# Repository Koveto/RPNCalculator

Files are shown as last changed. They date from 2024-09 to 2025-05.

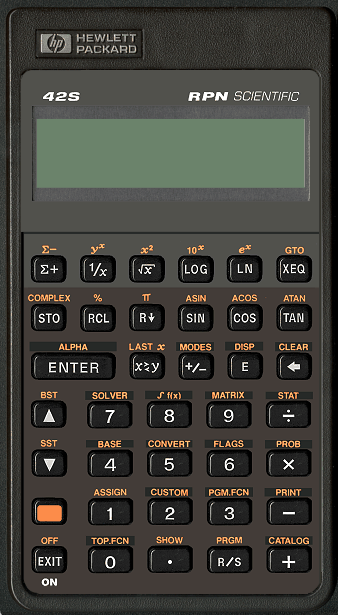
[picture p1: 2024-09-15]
background.png

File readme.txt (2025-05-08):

Reverse Polish Notation (RPN) Calculator

Contributors:
Kale Erickson
Kobe Goodwin
Gabe Wichmann

NDSU Senior Design project
ECE 403/405
Fall 2024 - Spring 2025
OneNote: https://ndusbpos-my.sharepoint.com/:o:/g/personal/kale_erickson_ndus_edu/EvFGwJnf-eBBiN7WtRWUvscBkYgOqBa3zW2gMm88qsdTBQ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

Project Description

HP-42S is a reverse polish notation (RPN) calculator championed by 
engineers around the world. RPN calculators sell for $400 and higher:
a forbidding price for college students. Our committee will design an
alternative HP-42S calculator that is affordable and reliable. Our 
RPN calculator solution will operate on mobile hardware powered by a
battery and disconnected from external devices. Our committee aims to
construct a RPN calculator engineering students could feasibly use on
exams. 

Instructions

1. Hold the button on the Raspberry Pi Pico
2. Plug the Pico into the computer
3. Drag "rp2-pico-micropython-doubleprecision-1-19.uf2" into the new directory
4. Unplug the Pico
5. Release the button
6. Plug the Pico into the computer
7. Use Thonny to save files in "program" to Pico

About the LCD

The program includes lcd.py and lcd_i2c.py.
lcd.py:
   communicates to the 20x4 LCD (using parallel interface)
lcd_i2c.py:
   NOT NECESSARY TO DOWNLOAD.
   used by an old PCB revision to communicate to its 16x2 LCD
   (using I2C protocol). 
To switch from one to the other,
   remove commented-out LCD_I2C import/initialization in main.py.
   comment out LCD import/initialization in main.py. 
Different LCD?
   the program only supports 20x4 parallel or 16x2 I2C.
   change ROWS and COLUMNS in lcd.py or lcd_i2c.py.
   revise lcd.write_to(...) commands in main.py and calculator.py.

Program your own game!

lcd.py is necessary.
Revise button_labels.py with your buttons and mapping.
Revise push_buttons.py if necessary.
Create your own main.py to read input and display output.

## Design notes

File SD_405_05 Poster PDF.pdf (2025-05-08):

# RPN Calculator

## Team Members: Kale Erickson, Kobe Goodwin, Gabe Wichmann

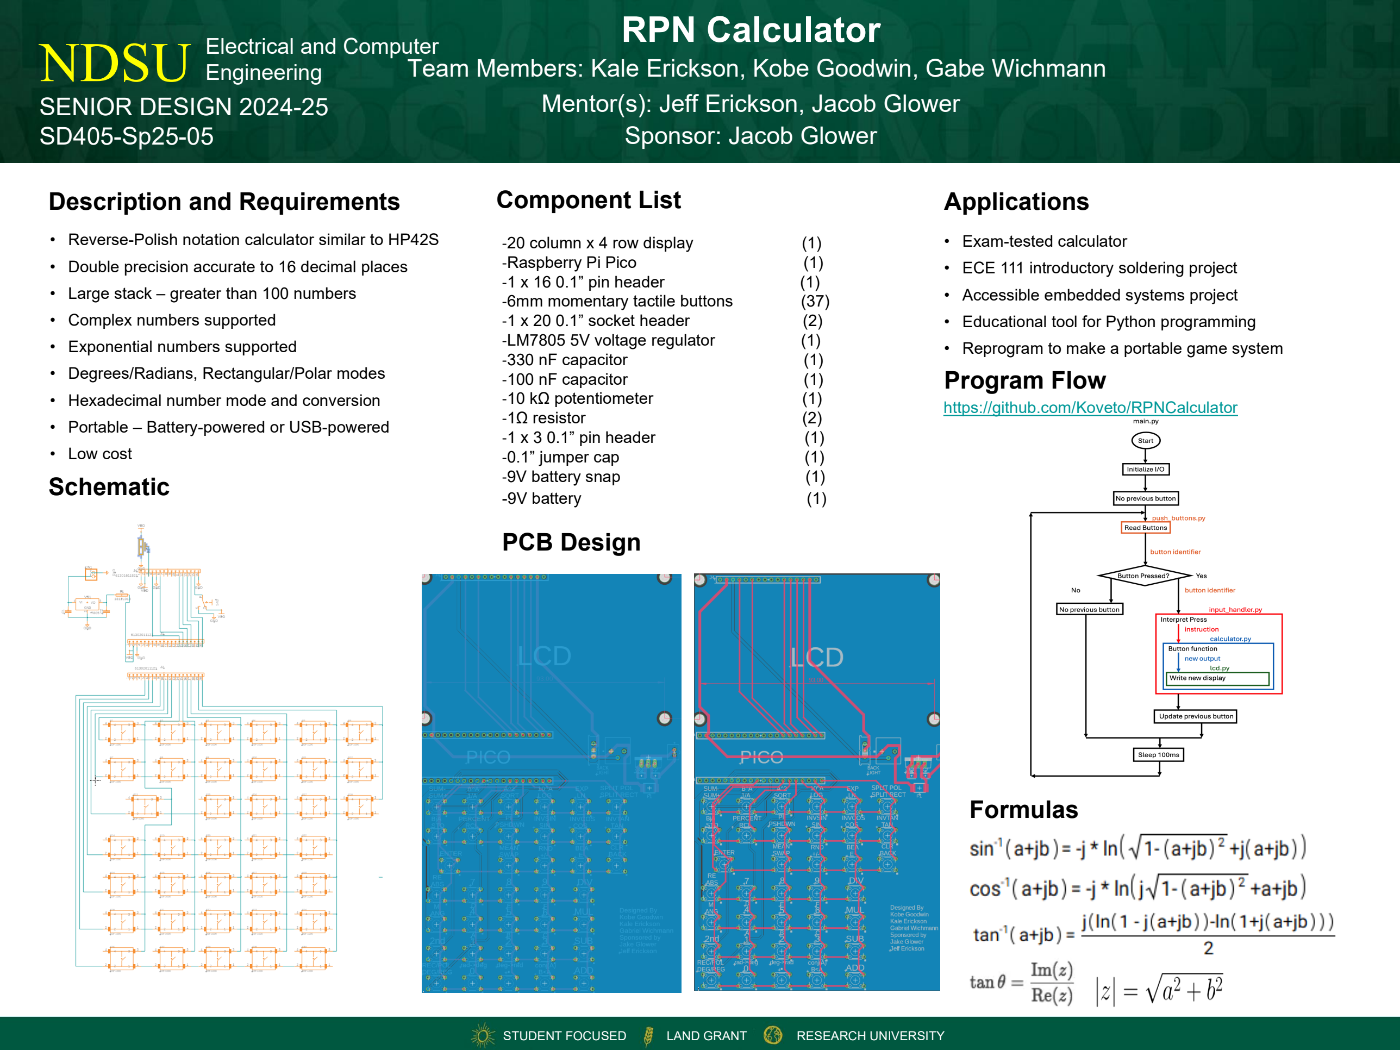
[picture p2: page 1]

STUDENT FOCUSED | LAND GRANT | RESEARCH UNIVERSITY

## Mentor(s): Jeff Erickson, Jacob Glower Sponsor: Jacob Glower

## SENIOR DESIGN 2024-25 SD405-Sp25-05

## Description and Requirements

- Reverse-Polish notation calculator similar to HP42S
- Double precision accurate to 16 decimal places
- Large stack – greater than 100 numbers
- Complex numbers supported
- Exponential numbers supported
- Degrees/Radians, Rectangular/Polar modes
- Hexadecimal number mode and conversion
- Portable – Battery-powered or USB-powered
- Low cost

## NDSU Electrical and Computer Engineering

Component List | Applications
| • Exam-tested calculator • ECE 111 introductory soldering project • Accessible embedded systems project • Educational tool for Python programming • Reprogram to make a portable game system
-20 column x 4 row display | (1)
-Raspberry Pi Pico | (1)
-1 x 16 0.1” pin header | (1)
-6mm momentary tactile buttons | (37)
-1 x 20 0.1” socket header | (2)
-LM7805 5V voltage regulator | (1)
-330 nF capacitor | (1)
-100 nF capacitor | (1)
-10 kΩ potentiometer | (1)
-1Ω resistor | (2)
-1 x 3 0.1” pin header | (1)
-0.1” jumper cap | (1)
-9V battery snap | (1)
-9V battery | (1)

## Program Flow

https://github.com/Koveto/RPNCalculator

## Schematic

## PCB Design

## Formulas

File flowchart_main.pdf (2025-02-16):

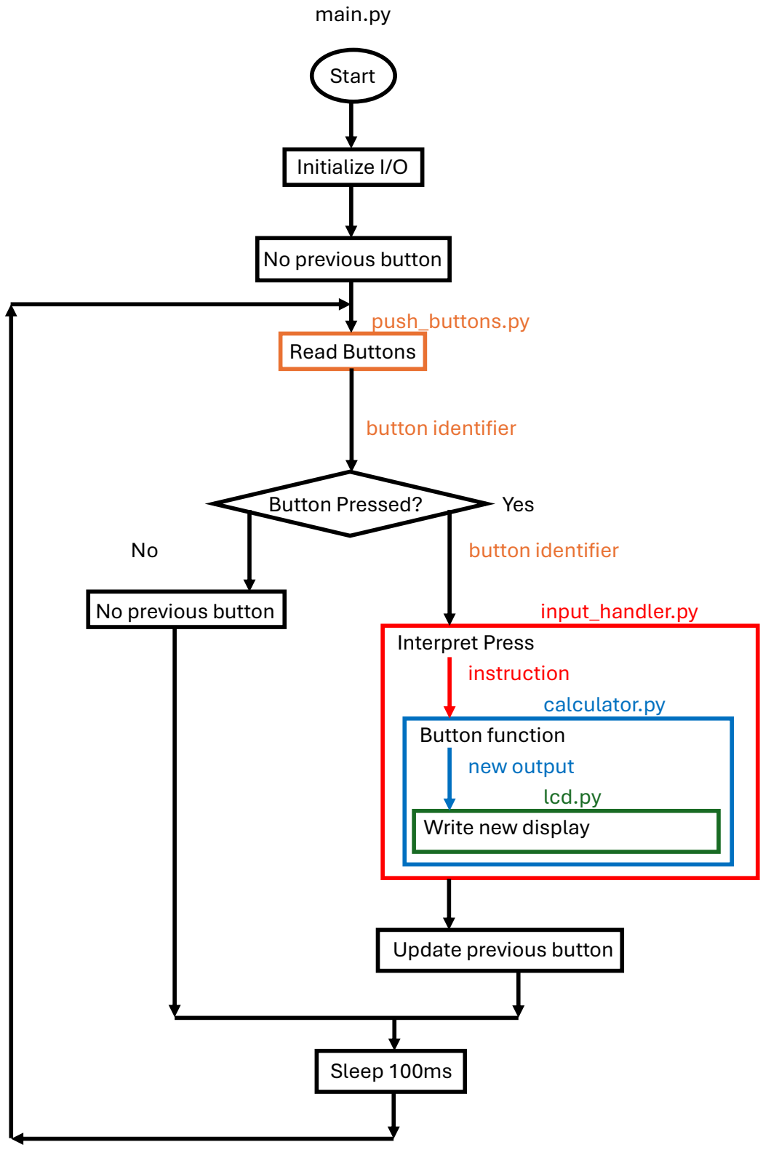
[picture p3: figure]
main.py; Start; Initialize I/O; No previous button; push_buttons.py Read Buttons; button identifier; Button Pressed?; Yes; input_handler.py; Interpret Press instruction calculator.py Button function new output lcd.py Write new display; Update previous button; Sleep 100ms

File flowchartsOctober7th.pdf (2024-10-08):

addition(Z)
Add top numbers from stack, subtract where Z = -1
Ex. | Z = 1 | (Addition) | Ex. | Z = -1 | (Subtraction)

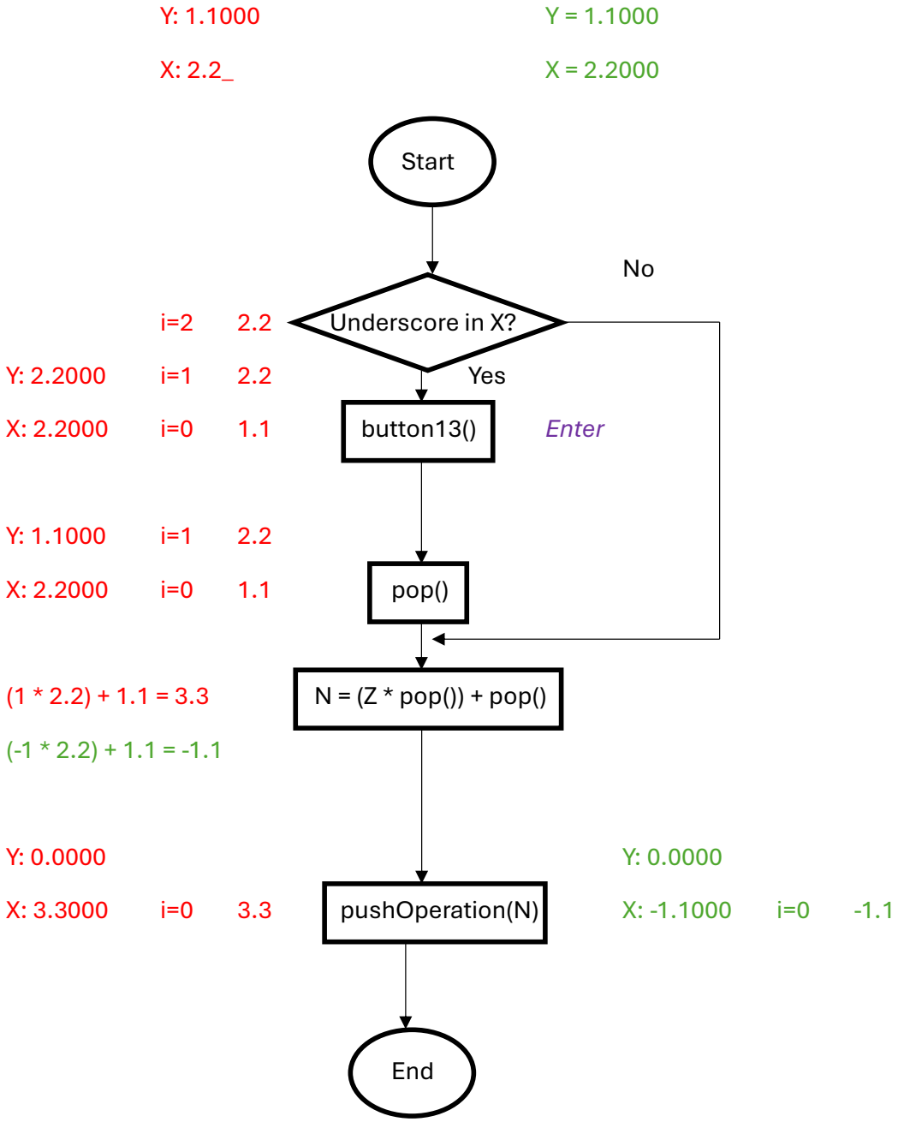
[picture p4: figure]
Start; Underscore in X?; Yes; button13(); Enter; pop(); pushOperation(N); End

(1 * 2.2) + 1.1 = 3.3 | N = (Z * pop()) + pop()

appendZeros(text)
Format text to add zeros
Ex. ”1” -> ”1.0000”
Ex. ”5.2” -> ”5.2000”
Ex. “3.14159” -> “3.14159”

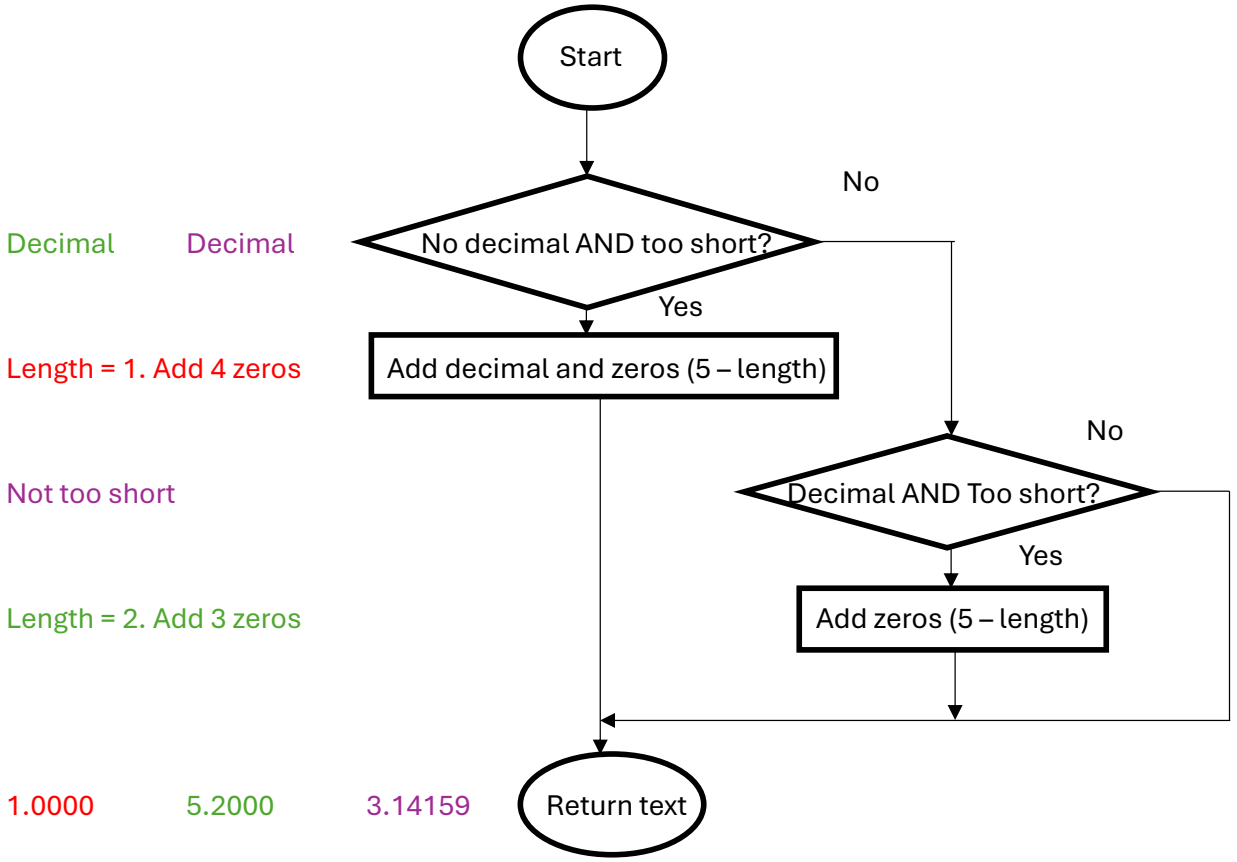
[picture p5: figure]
Start; Decimal; No decimal AND too short?; Yes; Not too short; Decimal AND Too short?; Return text

Length = 1. Add 4 zeros | Add decimal and zeros (5 – length)
Length = 2. Add 3 zeros | Add zeros (5 – length)

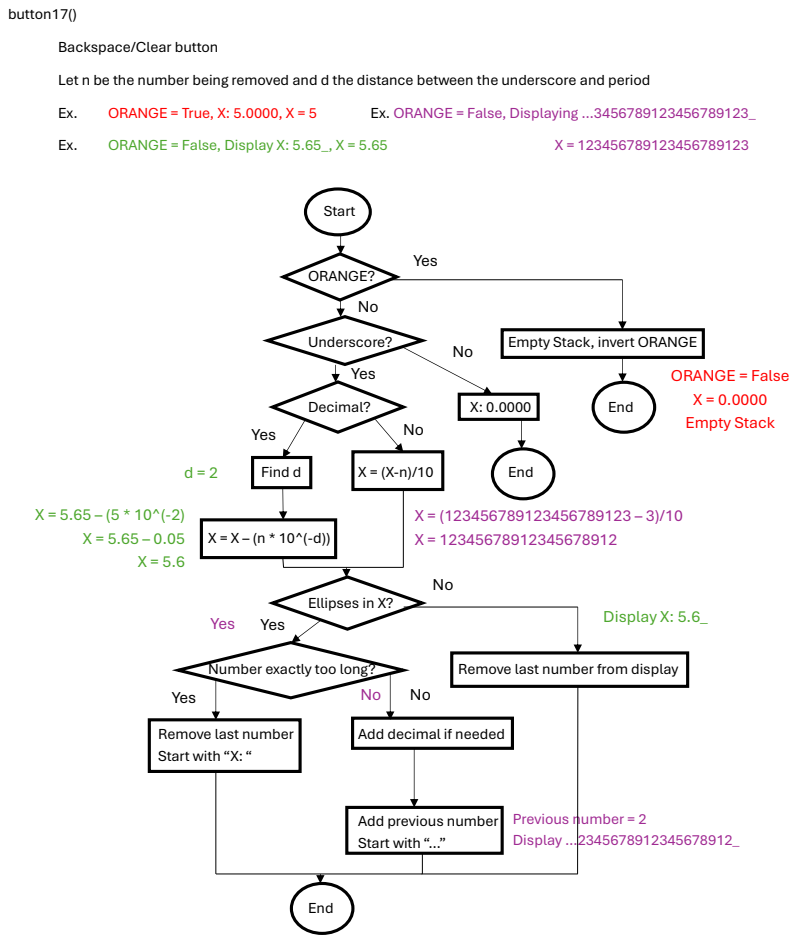
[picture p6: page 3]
Yes; ORANGE = False X = 0.0000 Empty Stack; Previous number = 2 Display …2345678912345678912_; ORANGE = True, X: 5.0000, X = 5; Ex. ORANGE = False, Displaying …3456789123456789123_; ORANGE = False, Display X: 5.65_, X = 5.65; Start; ORANGE?; Underscore?; Empty Stack, invert ORANGE; Decimal?; End; Find d; Ellipses in X?; Number exactly too long?; Remove last number from display; Remove last number; Add decimal if needed; Start with “X: “; Display X: 5.6_

button17()
Backspace/Clear button
Let n be the number being removed and d the distance between the underscore and period

Add previous number
Start with “…”

button22()
“Divide” button
Ex. | i=1 | 0 | Y: 2.0000 | Ex. | Y: 9.0000
i=0 | 2 | X: 0.0000 | i=0 | 9 | X: 3_
Outcome:
Divide By Zero | Y: 0.0000
X: 0.0000 | i=0 | 3 | X: 3.0000

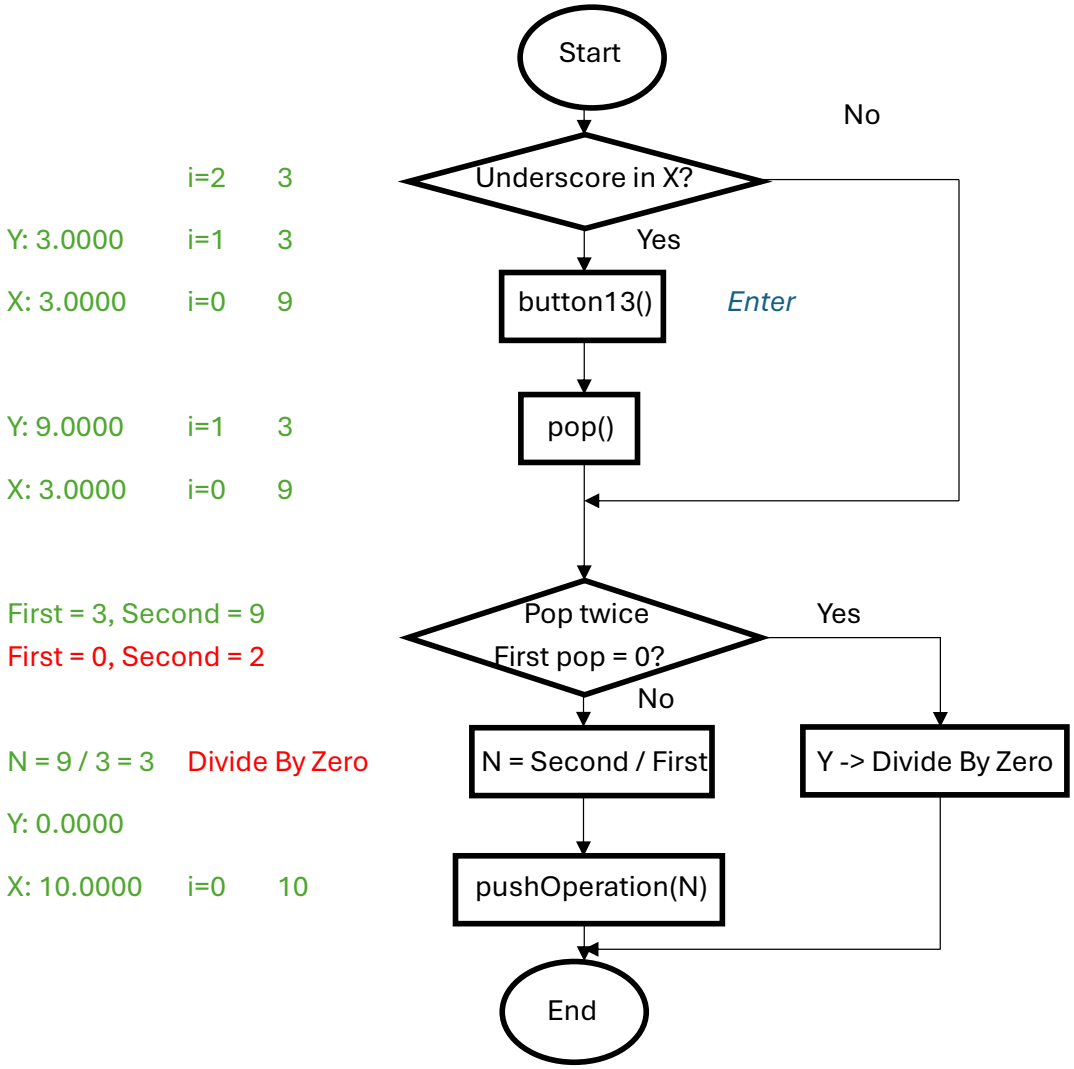
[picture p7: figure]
Start; Underscore in X?; Yes; button13(); Enter; pop(); First = 3, Second = 9; Pop twice; First = 0, Second = 2; First pop = 0?; pushOperation(N); End

N = 9 / 3 = 3 Divide By Zero | N = Second / First | Y -> Divide By Zero

button27()
"Multiply" button. Calls button13() and pop() to add the current number (if any) once to the stack. Pops twice from the stack and multiplies. Calls pushOperation(number) to update the stack and display.
Ex. | i=1 | 5 | Y: 2.0000 | Ex. | Y: 3.0000
i=0 | 2 | X: 5.0000 | i=0 | 3 | X: 4_
Outcome:
Y: 0.0000 | Y: 0.0000
i=0 | 10 | X: 10.0000 | i=0 | 12 | X: 12.0000

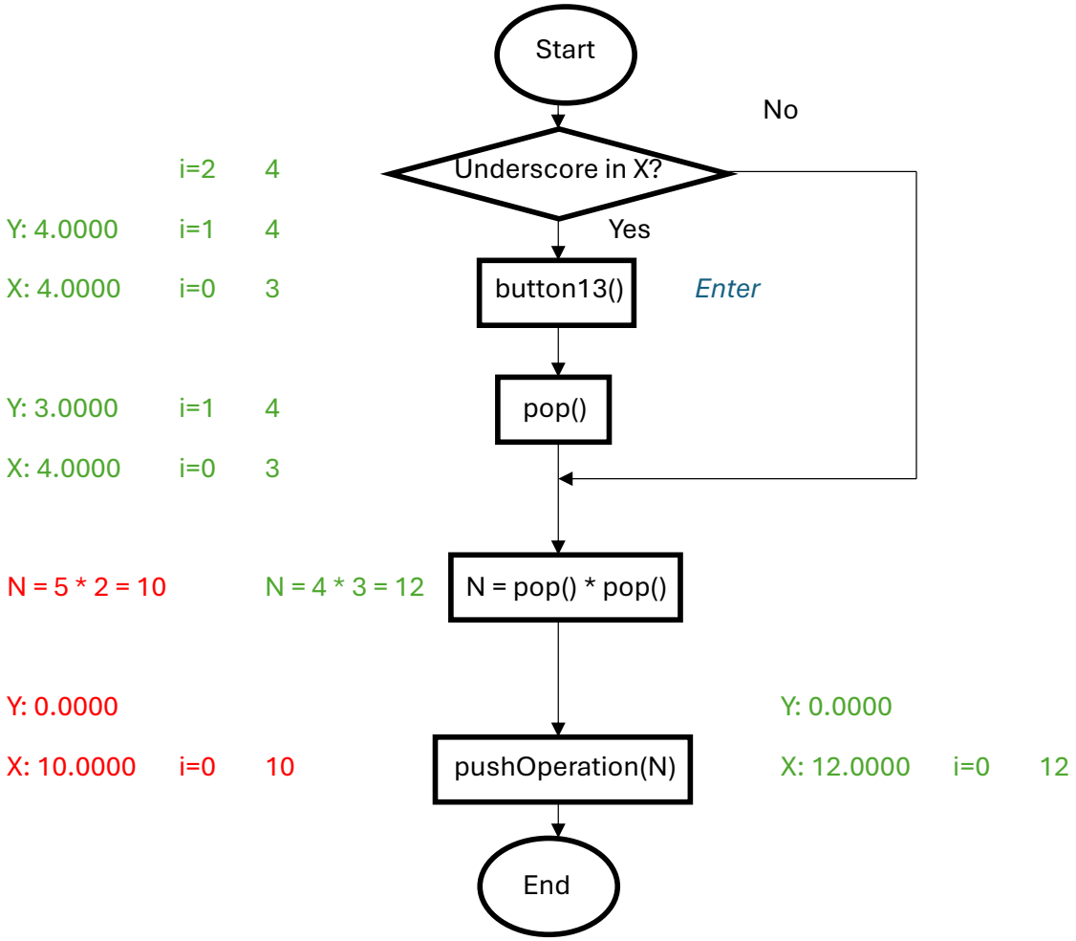
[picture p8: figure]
Start; Underscore in X?; Yes; button13(); Enter; pop(); pushOperation(N); End

N = 5 * 2 = 10 | N = 4 * 3 = 12 | N = pop() * pop()

button35()
Decimal button. Does nothing if a number is being input and already has a decimal place. Starts a new number at "0._" if no number is being input. Otherwise, adds "._" to the display and scrolls if necessary.
Ex. | X: 0.02_ | Ex. | X: 5.0000 | Ex. | …1234567891234567891_
numX = 0.02 | numX = 5 | numX = 1234567891234567891
Outcome:
| X: 0.02_ | | X: 0._ | | …234567891234567891._
numX = 0.02 | numX = 0 | numX = 1234567891234567891

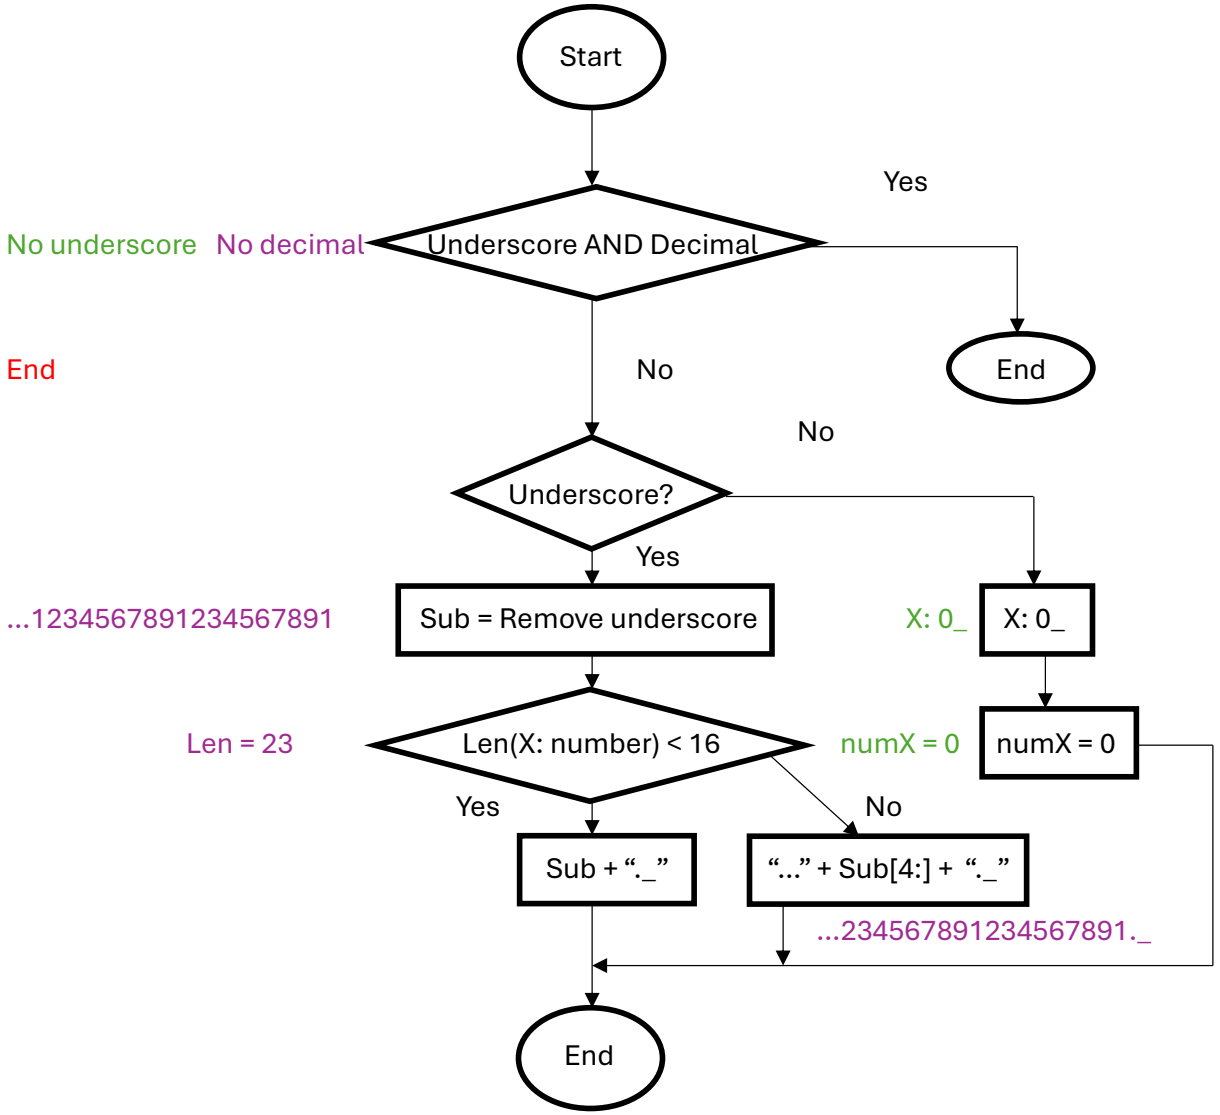
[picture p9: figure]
Start; Yes; No underscore No decimal; Underscore AND Decimal; End; Underscore?; Sub = Remove underscore; Len = 23; Len(X: number) < 16; numX = 0; Sub + “._”; “…” + Sub[4:] + “._”

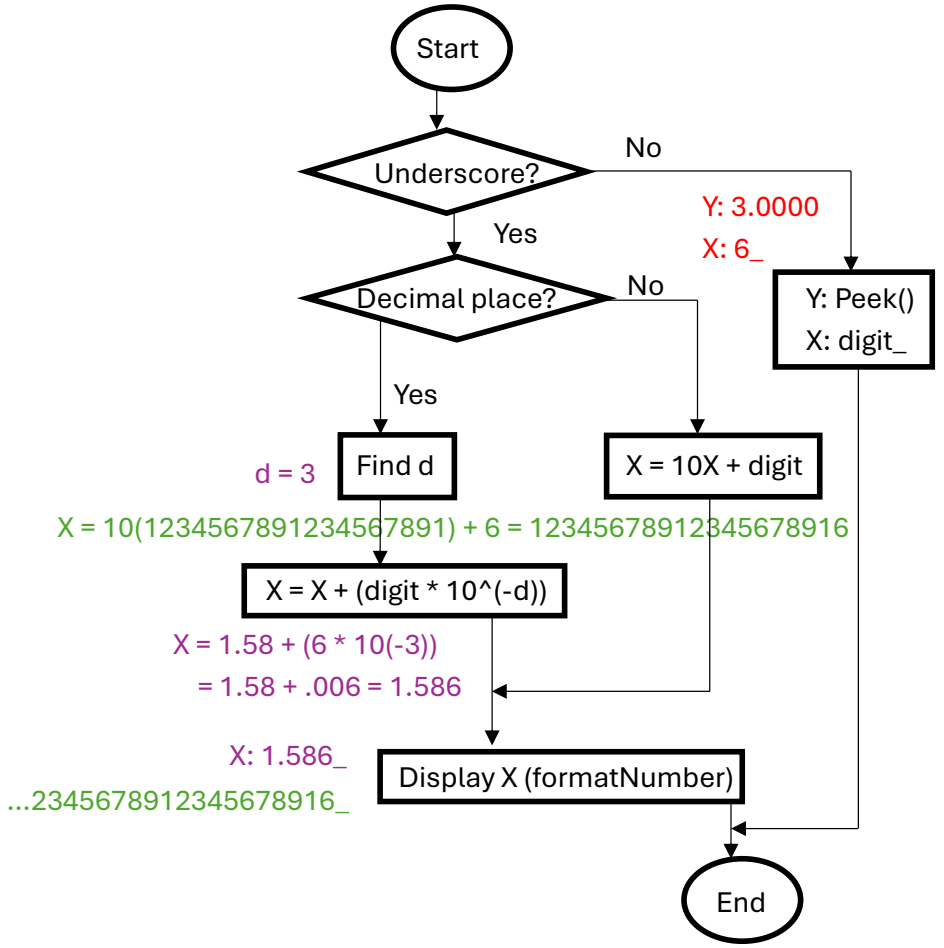
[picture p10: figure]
Yes; Start; Underscore?; Decimal place?; Y: Peek(); X: digit_; Find d; X = 10X + digit; X = X + (digit * 10^(-d)); Display X (formatNumber); End

X = 10(1234567891234567891) + 6 = 12345678912345678916

numberPressed(digit)…
Given a digit 0-9, update X and the display.
Let d be the distance between “.” And “_” . Assume digit = 6.
Ex. | i = 0 3 | X: 3.0000 | Ex. | X = 1234567891234567891
Ex. | X: 1.58_ | X = 1.58 | | …1234567891234567891_

pushOperation(number)

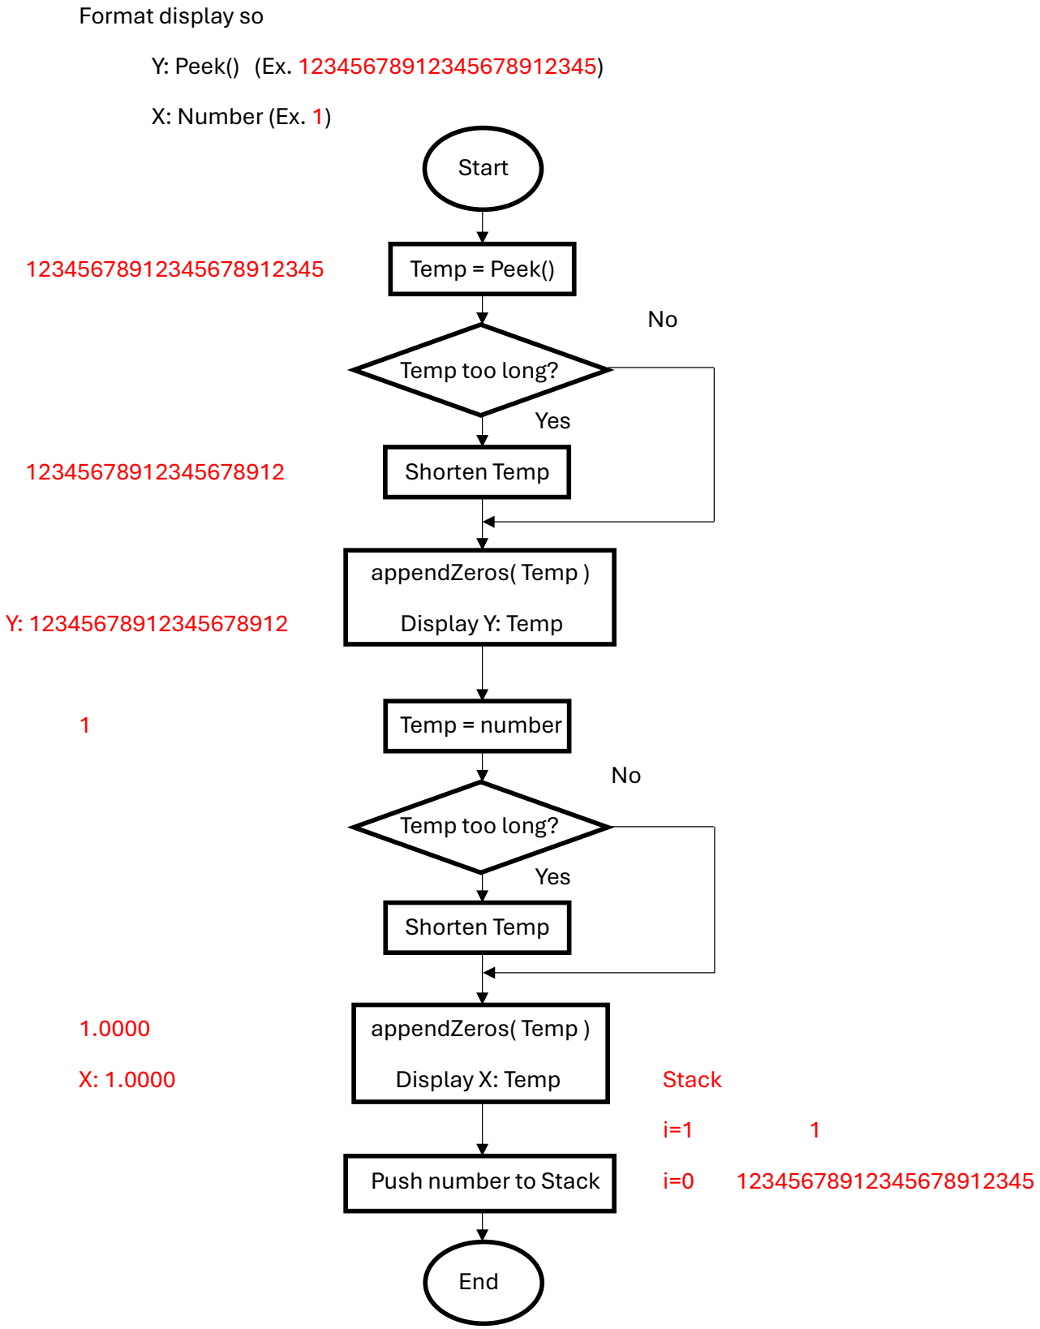
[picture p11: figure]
Format display so; Y: Peek() (Ex. 12345678912345678912345); X: Number (Ex. 1); Start; Temp = Peek(); Temp too long?; Yes; Shorten Temp; appendZeros( Temp ); Display Y: Temp; Temp = number; Display X: Temp; Stack; Push number to Stack; End

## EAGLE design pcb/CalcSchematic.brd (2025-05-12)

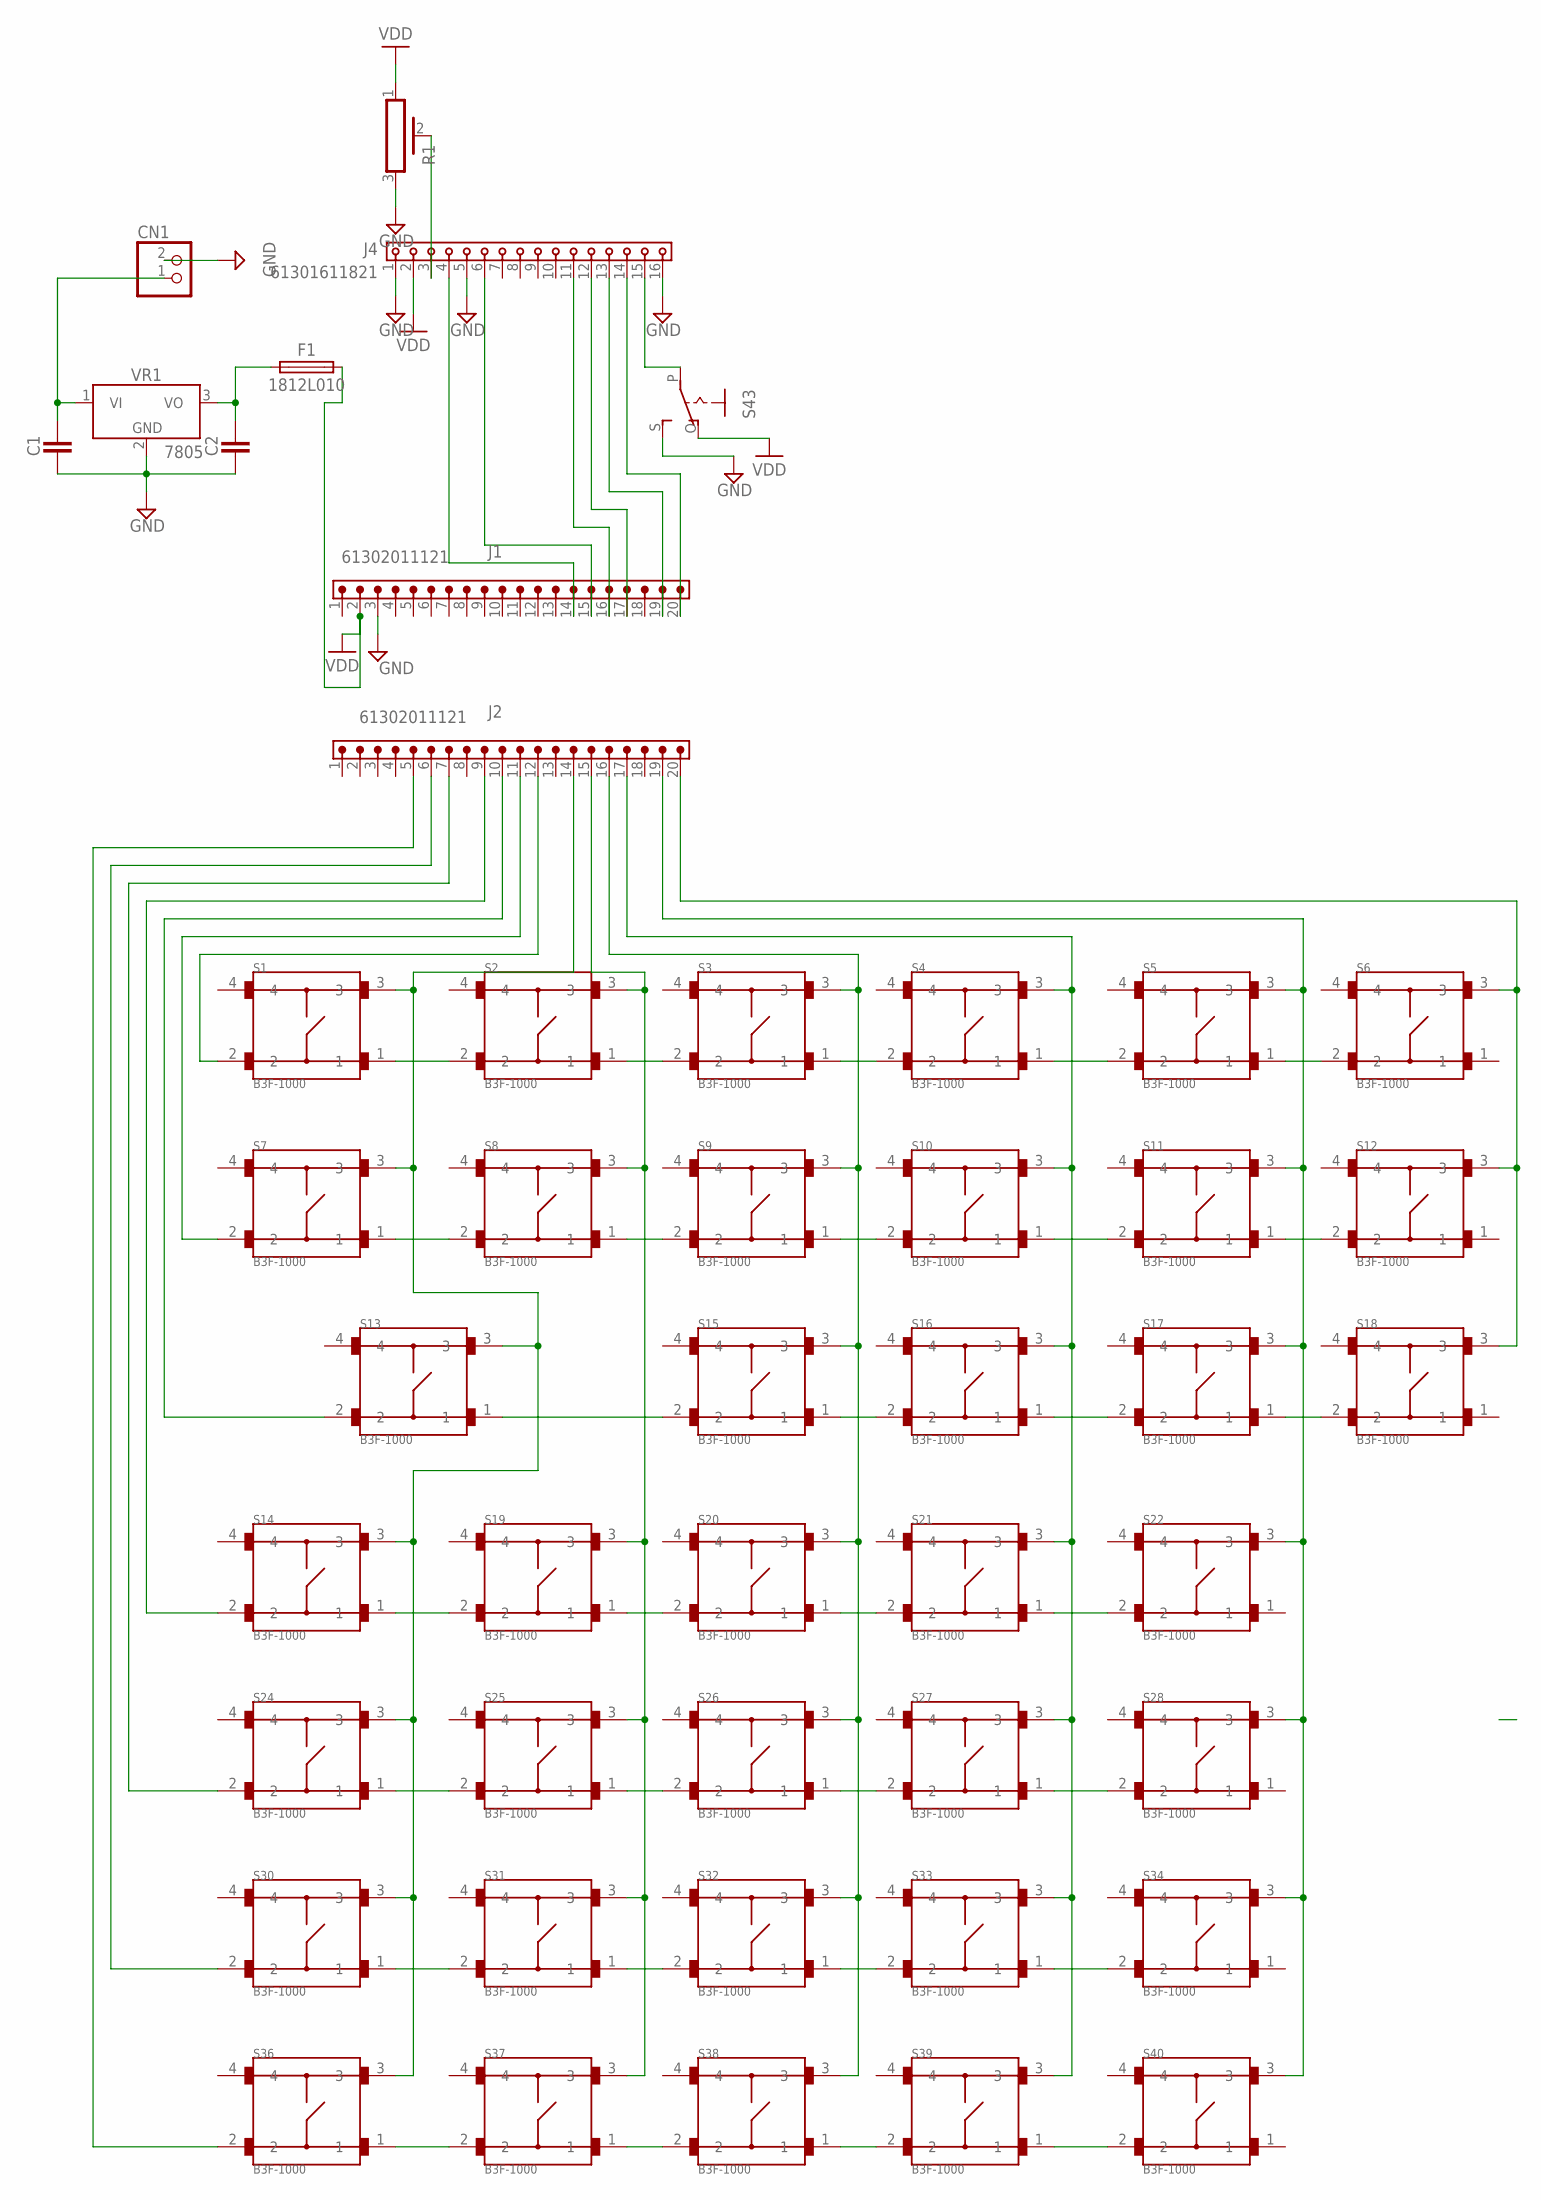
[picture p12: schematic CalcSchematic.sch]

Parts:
C1, C2: CAPACITOR_CHIP-1206(3216-METRIC); CAPC3216X135
CN1: JST_2PIN-THM; JST-PH-2-THM
F1: 1812L010; FUSC4532X125
J1, J2: 61302011121
J4: 61301611821
R1: POT_PV36P; PV36P
S1, S2, S3, S4, S5, S6, S7, S8, S9, S10, S11, S12, S13, S14, S15, S16, S17, S18, S19, S20, S21, S22, S24, S25, S26, S27, S28, S30, S31, S32, S33, S34, S36, S37, S38, S39, S40: B3F-1000; SW_B3F-1000
S43: EG1218S; EG1218
VR1: 7805; TO220V

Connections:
GND: C1.2, C2.2, CN1.2 (1), J1.3, J4.1, J4.5, J4.16, R1.3, S43.S, VR1.2 (GND)
unnamed: S1.1, S2.2
unnamed: S2.1, S3.2
unnamed: S3.1, S4.2
unnamed: S4.1, S5.2
unnamed: S5.1, S6.2
unnamed: S7.1, S8.2
unnamed: S8.1, S9.2
unnamed: S9.1, S10.2
unnamed: S10.1, S11.2
unnamed: S11.1, S12.2
unnamed: S13.1, S15.2
unnamed: S15.1, S16.2
unnamed: S16.1, S17.2
unnamed: S17.1, S18.2
unnamed: S14.1, S19.2
unnamed: S19.1, S20.2
unnamed: S20.1, S21.2
unnamed: S21.1, S22.2
unnamed: S24.1, S25.2
unnamed: S25.1, S26.2
unnamed: S26.1, S27.2
unnamed: S27.1, S28.2
unnamed: C2.1, F1.1, VR1.3 (VO)
unnamed: S30.1, S31.2
unnamed: S31.1, S32.2
unnamed: S32.1, S33.2
unnamed: S33.1, S34.2
unnamed: S36.1, S37.2
unnamed: S37.1, S38.2
unnamed: S38.1, S39.2
unnamed: S39.1, S40.2
unnamed: J2.14, S1.3, S7.3, S13.3, S14.3, S24.3, S30.3, S36.3
unnamed: J2.15, S2.3, S8.3, S19.3, S25.3, S31.3, S37.3
unnamed: J2.16, S3.3, S9.3, S15.3, S20.3, S26.3, S32.3, S38.3
unnamed: J2.17, S4.3, S10.3, S16.3, S21.3, S27.3, S33.3, S39.3
unnamed: J2.19, S5.3, S11.3, S17.3, S22.3, S28.3, S34.3, S40.3
unnamed: J2.20, S6.3, S12.3, S18.3
unnamed: J2.12, S1.2
unnamed: J2.11, S7.2
unnamed: J2.10, S13.2
unnamed: J2.9, S14.2
unnamed: J2.7, S24.2
unnamed: J2.6, S30.2
unnamed: J2.5, S36.2
unnamed: J4.3, R1.2
unnamed: J1.14, J4.4
unnamed: J1.15, J4.6
unnamed: J1.16, J4.11
unnamed: J1.17, J4.12
unnamed: J1.19, J4.13
unnamed: J1.20, J4.14
unnamed: J4.15, S43.P
unnamed: C1.1, CN1.1 (2), VR1.1 (VI)
VDD: F1.2, J1.2, J4.2, R1.1, S43.O

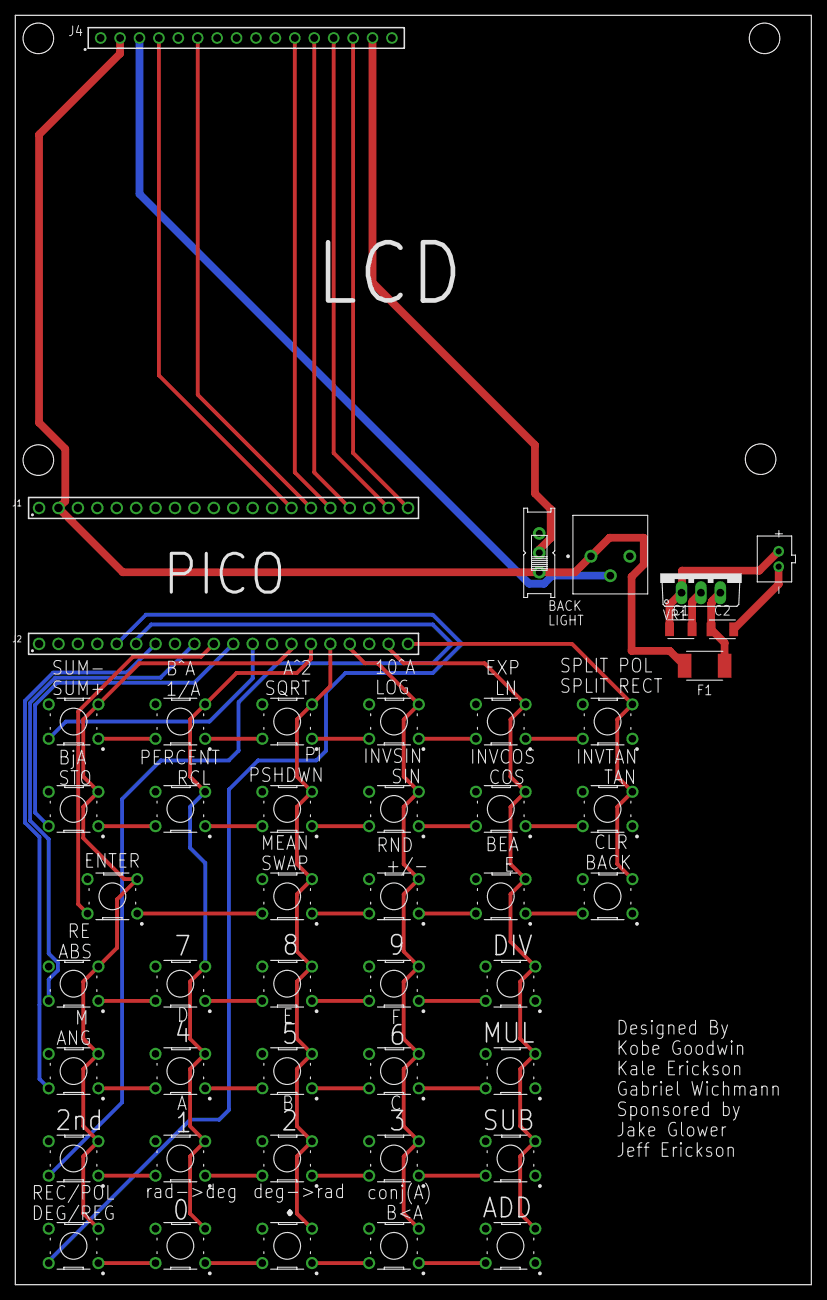
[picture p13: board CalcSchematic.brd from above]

Board: 2 copper layers, 104.1 x 166.0 mm, 47 parts (0 on the bottom side), 55 nets.

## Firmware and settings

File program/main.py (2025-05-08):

"""
main.py
Kobe Goodwin
5/8/2025

Initializes I/O, polls button input, interprets presses, updates LCD.
"""

#from lcd_i2c import LCD_I2C
from lcd import LCD
from push_buttons import PushButtons
from input_handler import InputHandler
from button_labels import ButtonLabels
from machine import Pin
from time import sleep_ms
import config

# Pinout assignment
# LCD
RS = 21
EN = 20
D4 = 19
D5 = 18
D6 = 17
D7 = 16
SDA = 0
SCL = 1
ANGLE    = [0x00, 0x01, 0x03, 0x06, 0x0C, 0x18, 0x1F, 0x00]
PI       = [0x00, 0x00, 0x1F, 0x0A, 0x0A, 0x0A, 0x0B, 0x00]
SQUARE   = [0x03, 0x05, 0x01, 0x02, 0x07, 0x00, 0x00, 0x00]
ROOT     = [0x04, 0x06, 0x05, 0x04, 0x04, 0x14, 0x0C, 0x04]
DIVIDE   = [0x00, 0x04, 0x00, 0x1F, 0x00, 0x04, 0x00, 0x00]
MULTIPLY = [0x00, 0x11, 0x0A, 0x04, 0x0A, 0x11, 0x00, 0x00]
# Button Array
BUTTON_ROWS = [3, 4, 5, 6, 7, 8, 9]
BUTTON_COLS = [10, 11, 12, 13, 14, 15]

def find_button_index(label):
    """
    Finds the row, column index of a BUTTON_LABELS_A label
    
    Args:
        label (str): The BUTTON_LABELS_A label to retrieve index of
    
    Returns:
        tuple (int, int): The index of the label
    """
    for row_index, row in enumerate(ButtonLabels.BUTTON_LABELS_A):
        if label in row:
            col_index = row.index(label)
            return (row_index, col_index)
    return (0, 0)

def display_settings(lcd):
    """
    Displays config settings
    
    Args:
        lcd (LCD): The display being written to
        
    Returns:
        None
    """
    if ((lcd.rows == 4) and \
        (lcd.columns == 20)):
        
        if (config.orient_top_bottom):
            lcd.write_at(17, 3, "Deg" if config.degrees else "Rad")
        else:
            lcd.write_at(17, 0, "Deg" if config.degrees else "Rad")
            
        if (config.orient_top_bottom):
            lcd.write_at(12, 3, "Polr" if config.polar else "Rect")
        else:
            lcd.write_at(12, 0, "Polr" if config.polar else "Rect")
            
        if (config.orient_top_bottom):
            lcd.write_at(8, 3, "Hex" if config.hexadecimal else "Dec")
        else:
            lcd.write_at(8, 0, "Hex" if config.hexadecimal else "Dec")
            
        if (config.orient_top_bottom):
            lcd.write_at(4, 3, "INF" if config.scientific else "RPN")
        else:
            lcd.write_at(4, 0, "INF" if config.scientific else "RPN")
            
        if (config.button_mode):
            if (config.orient_top_bottom):
                lcd.write_at(0, 3, "2nd")
            else:
                lcd.write_at(0, 0, "2nd")
        else:
            if (config.orient_top_bottom):
                lcd.write_at(0, 3, "   ")
            else:
                lcd.write_at(0, 0, "   ")
                
    elif ((lcd.rows == 2) and \
          (lcd.columns == 16)):
        
        if (config.button_mode):
            lcd.write_at(0, 0, "2nd")
        else:
            lcd.write_at(0, 0, "Y: ")

def main():
    """
    Initializes the I/O
    Polls for button input
    Debounces push button input
    Calls InputHandler for new button presses
    Updates the LCD with new output.
    
    Returns:
        None
    """
    # Initialize I/O
    lcd = LCD(RS, EN, D4, D5, D6, D7)
    #lcd = LCD_I2C(SDA, SCL)
    buttons = PushButtons(BUTTON_ROWS, BUTTON_COLS)
    handler = InputHandler(lcd)
    
    # Custom characters
    lcd.custom_char(0, bytearray(ANGLE))
    lcd.custom_char(1, bytearray(PI))
    lcd.custom_char(2, bytearray(SQUARE))
    lcd.custom_char(3, bytearray(ROOT))
    lcd.custom_char(4, bytearray(DIVIDE))
    lcd.custom_char(5, bytearray(MULTIPLY))
    
    # Initial LCD output
    if ((lcd.rows == 4) and \
        (lcd.columns == 20)):
        lcd.write_at(0, 1, "Z: 0")
        lcd.write_at(0, 2, "Y: 0")
        lcd.write_at(0, 3, "X: 0")
        
    elif ((lcd.rows == 2) and \
          (lcd.columns == 16)):
        lcd.write_at(0, 0, "Y: 0")
        lcd.write_at(0, 1, "X: 0")
    
    # Prevent repeated presses
    previous_press = None
    index_previous = (0, 0)

    # Main loop
    while True:
        button_press = buttons.get_button()
        
        # Determine which function was pressed
        if button_press:
            index_previous = find_button_index(previous_press)
            
        # A new (debounced) button function was pressed...
        if button_press and (button_press != previous_press) and \
           (button_press != ButtonLabels.BUTTON_LABELS_A[index_previous[0]][index_previous[1]]):
            
            # If "2nd"...
            if (button_press == ButtonLabels.ALTERNATE_FUNCTIONS):
                if (config.button_mode):
                    new_buttons = ButtonLabels.BUTTON_LABELS_A
                else:
                    new_buttons = ButtonLabels.BUTTON_LABELS_B
                config.button_mode = not config.button_mode
                buttons.set_key_list(new_buttons)
                
            # Any button that isn't "2nd"...
            else:
                if (config.button_mode):
                    config.button_mode = False
                    buttons.set_key_list(ButtonLabels.BUTTON_LABELS_A)
                handler.interpret_button_press(button_press)
            previous_press = button_press
            
        # None for debouncing
        elif button_press is None:
            previous_press = None
            
        # Update settings    
        display_settings(lcd)
            
        sleep_ms(100)

if __name__ == "__main__":
    main()

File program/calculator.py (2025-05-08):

"""
calculator.py
Kobe Goodwin
5/6/2025

Keeps track of the stack and user input.
Displays new output to screen.
"""

import math
import cmath
from stack import Stack
from button_labels import ButtonLabels as b
import config
import os

FILENAME = "variables.txt"

"""
Unique error to be inherited
"""
class CustomError(Exception):
    pass

"""
Domain error
"""
class UndefinedError(CustomError):
    def __init__(self, message):
        self.message = message
        super().__init__(self.message)

class Calculator:
    def __init__(self, lcd):
        """
        Initializes the Calculator with the given LCD instance.

        Args:
            lcd (LCD): draw text to screen
            
        Returns:
            instance of Calculator
        """
        self.lcd = lcd
        self.stack = Stack()
        self.current_input = ""
        self.input_in_progress = False
        self.store = [0.0]*6
        self.just_pressed_enter = False
        if ((lcd.rows == 4) and \
            (lcd.columns == 20)):
            if (config.orient_top_bottom):
                self.lcd.write_at(0, 0, "X: 0")
                self.lcd.write_at(0, 1, "Y: 0")
                self.lcd.write_at(0, 2, "Z: 0")
            else:
                self.lcd.write_at(0, 1, "Z: 0")
                self.lcd.write_at(0, 2, "Y: 0")
                self.lcd.write_at(0, 3, "X: 0")
        elif ((lcd.rows == 2) and \
              (lcd.columns == 16)):
            self.lcd.write_at(0, 0, "Y: 0")
            self.lcd.write_at(0, 1, "X: 0")
        
    def roll(self):
        """
        Roll stack down: X to bottom, Y to top
        
        Returns:
            None
        """
        self._complete_input()
        if (self.stack.is_empty()):
            return
        self.stack = self.stack + self.stack.pop()
        
    def store_prompt(self):
        """
        Start the store mode
        
        Returns:
            None
        """
        self._complete_input()
        config.storing = True
        
    def store_variable(self, index):
        """
        Store the identifier A-F
        
        Returns:
            None
        """
        try:
            file = open(FILENAME, "r")
            contents = file.read().strip()
            file.close()
        except OSError:
            with open(FILENAME, "w") as file:
                file.write(",".join(["0"] * 6))
            contents = ",".join(["0"] * 6)
        values = contents.split(",")
        values[index] = str(self.stack.peek())
        with open(FILENAME, "w") as file:
            file.write(",".join(values))
        
    def recall_prompt(self):
        """
        Start the recall mode
        
        Returns:
            None
        """
        self._complete_input()
        config.recalling = True
        
    def recall_variable(self, index):
        """
        Recall the identifier A-F
        
        Returns:
            None
        """
        try:
            file = open(FILENAME, "r")
            contents = file.read().strip()
            file.close()
        except OSError:
            with open(FILENAME, "w") as file:
                file.write(",".join(["0"] * 6))
            contents = ",".join(["0"] * 6)
        values = contents.split(",")
        value = values[index]
        if "j" in value:
            self.stack.push(self._str_to_complex(value))
        else:
            self.stack.push(float(value))
            
    def _str_to_complex(self, s):
        """
        Converts a string in the form '(real+imaginaryj)' to a complex number.

        Args:
            s (str): The string representing a complex number '(5+5j)'.

        Returns:
            complex: The complex number represented by the string.
        """
        s = s.strip()
        if s.startswith("(") and s.endswith(")"):
            s = s[1:-1]

        s = s.replace("j", "")
        real = 0.0
        imaginary = 0.0

        if "+" in s:
            parts = s.split("+")
            real = float(parts[0])
            imaginary = float(parts[1])
        elif "-" in s[1:]:
            flag = False
            n = s
            if (s[0] == "-"):
                n = s[1:]
                flag = True
            parts = n.split("-")
            if flag:
                parts[0] = "-" + parts[0]
            real = float(parts[0])
            imaginary = -float(parts[1])
        else:
            if s:
                imaginary = float(s)

        return complex(real, imaginary)
    
    def delete(self):
        """
        Pops the top number
        
        Returns:
            None
        """
        self._complete_input()
        self.stack.pop()

    def handle_complex_number(self, polar = False):
        """
        Handles complex number input by creating a complex number from the
        top two numbers on the stack and updates the display.
        
        Args:
            polar (bool): True for interpreting Y<X.
                          False for Y+jX
                          
        Returns:
            None
        """
        if (polar):
            config.polar = True
        else:
            config.polar = False
            
        if self.stack.size() == 0:
            self.stack.push(0.0)
        
        self._complete_input()

        if (type(self.stack.peek()) == complex):
            if (polar):
                self.split_complex_polar()
            else:
                self.split_complex_rect()
            return

        x = self.stack.pop()
        y = self.stack.pop()
        
        if (polar):
            if (config.degrees):
                if (type(x) == complex):
                    real = y * cmath.cos(x*math.pi/180)
                else:
                    real = y * math.cos(x*math.pi/180)
                if (type(y) == complex):
                    imag = y * cmath.sin(x*math.pi/180)
                else:
                    imag = y * math.sin(x*math.pi/180)
                complex_number = complex(real, imag)
            else:
                if (type(x) == complex):
                    real = y * cmath.cos(x)
                else:
                    real = y * math.cos(x)
                if (type(y) == complex):
                    imag = y * cmath.sin(x)
                else:
                    imag = y * math.sin(x)
                complex_number = complex(real, imag)
        else:
            complex_number = complex(y, x)
        self.stack.push(complex_number)


    def handle_digit_input(self, digit):
        """
        Handles digit input, updating the current input and LCD display.
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

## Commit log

2024-09-15 UI Button detection
2024-10-06 Backspace/Enter methods resolved for numbers extending beyond DIGITS_ON_SCREEN
    [main.py]
2024-10-06 Orange/Clear button
2024-10-06 pushOperation flowchart
2024-10-06 appendZeros flowchart
2024-10-06 addition flowchart
2024-10-06 button35 flowchart
2024-10-06 button27 flowchart
2024-10-06 button22 flowchart
2024-10-06 button17 flowchart
2024-10-08 numberPressed flowchart
2024-10-08 Combined flowcharts pdf
2024-10-28 Pico button detection
2024-10-29 Keypad + Button input
2024-10-29 Task 1 Functions to Pico
2024-10-29 Fourth button: Orange/Clear
2024-12-15 Push button inverter
2024-12-20 Button Array
2025-02-11 I2C Connection
2025-02-13 Trig, Log, Negate, Reciprocal, Swap
    [calculator.py, main.py]
2025-02-16 Main flowchart
2025-02-17 Push Button Flowchart
2025-03-03 Button Labels added
2025-03-03 Button Labels
2025-04-28 Fixed orient bug. Add hex support
    [button_labels.py, calculator.py, input_handler.py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]
2025-05-07 Condensed parallel LCD functions to lcd.py. Integrated old I2C code so program can run on old PCB
2025-05-08 Simplified deprecated I2C functions into lcd_i2c.py. Program now works for both old and new PCB
2025-05-08 Button functions pdf
2025-05-12 pcb files
    [CalcSchematic.brd, CalcSchematic.sch]

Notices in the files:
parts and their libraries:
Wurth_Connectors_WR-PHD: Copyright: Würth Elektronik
